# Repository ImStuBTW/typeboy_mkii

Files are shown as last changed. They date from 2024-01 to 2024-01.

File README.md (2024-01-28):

# The TypeBoy Mk II

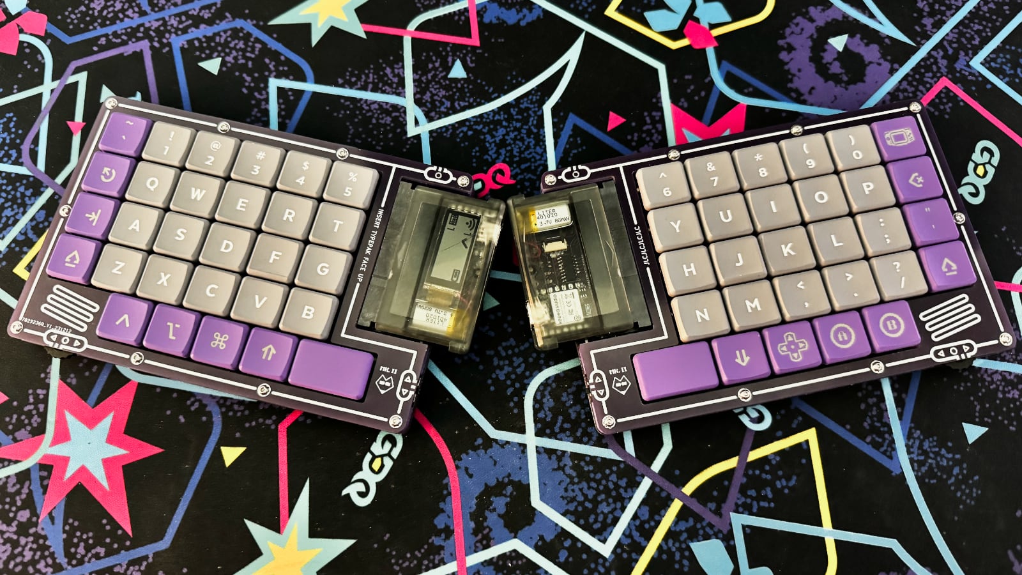
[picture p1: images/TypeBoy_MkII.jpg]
The TypeBoy Mark II Keyboard


The Mark II is an updated design to the original TypeBoy keyboard. It continues to leverage the "TypePak" cartridge to house the keyboard's microcontroller and other support circuitry. This revision of the TypeBoy uses a more traditional ortholinear keyboard layout, and replaces the previous 3D printed design with a PCB sandwich approach. For more information on the keyboard's background, please feel free to check out this companying blog post.

## Primary Features

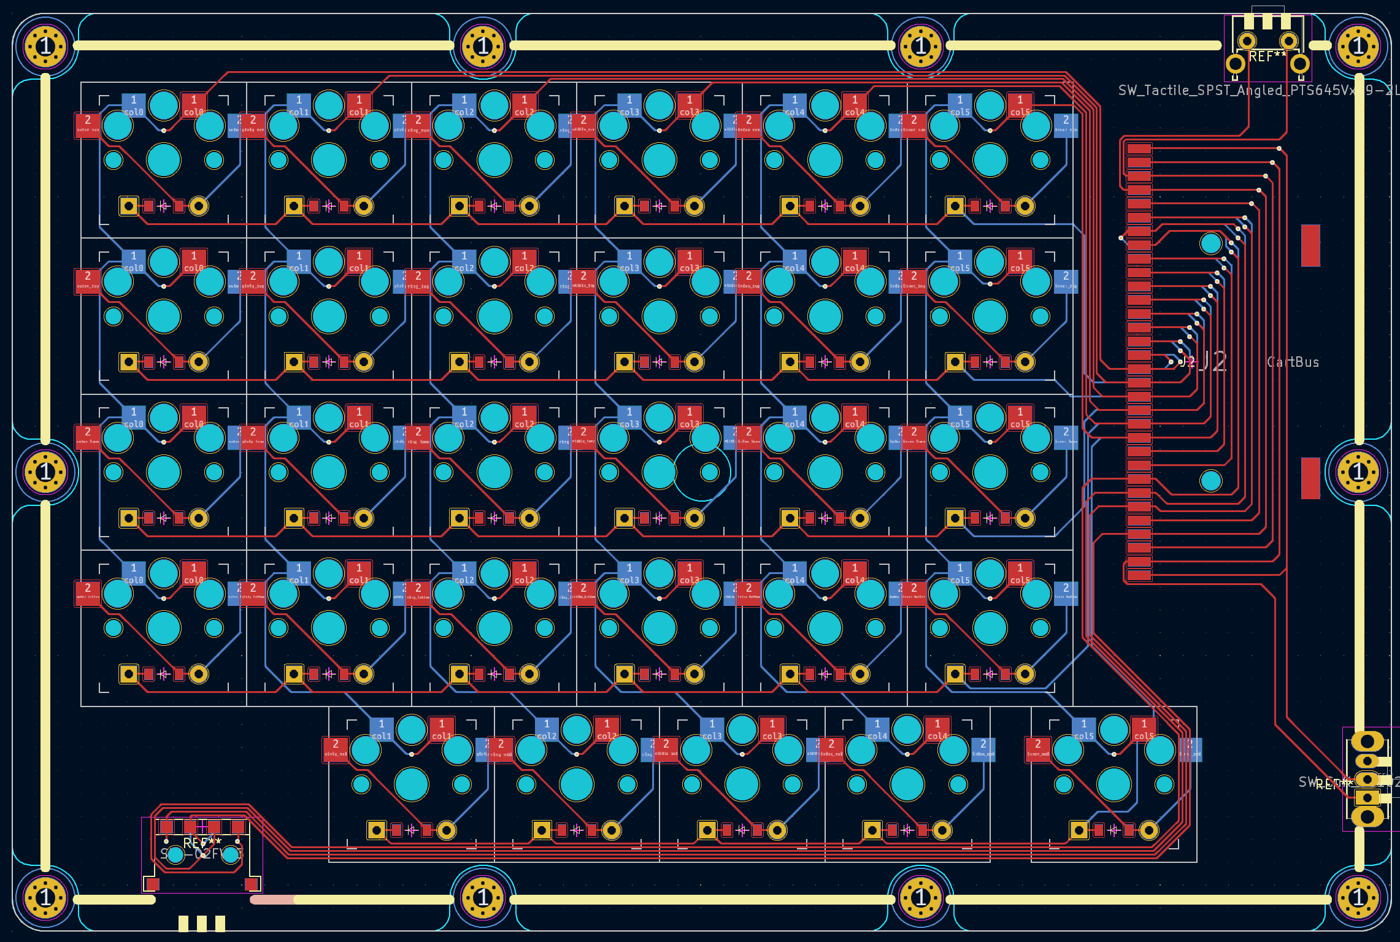
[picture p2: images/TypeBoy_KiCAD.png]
The TypeBoy Mk II KiCAD Diagram


* TypeBoy Cartridge Support (Integrated XAIO BLE, LiPo Battery, Shift Register, and Sharp Memory Display)
* 6x4+5 ortholinear layout with a staggered modifier row and enlarged space keys.
* Choc v1 switches with Choc spacing.
* SIQ-02FVS3 thumb wheel encoders (with pushbutton support).
* PCB sandwich design.
* ZMK support.

## Ergogen Outputs

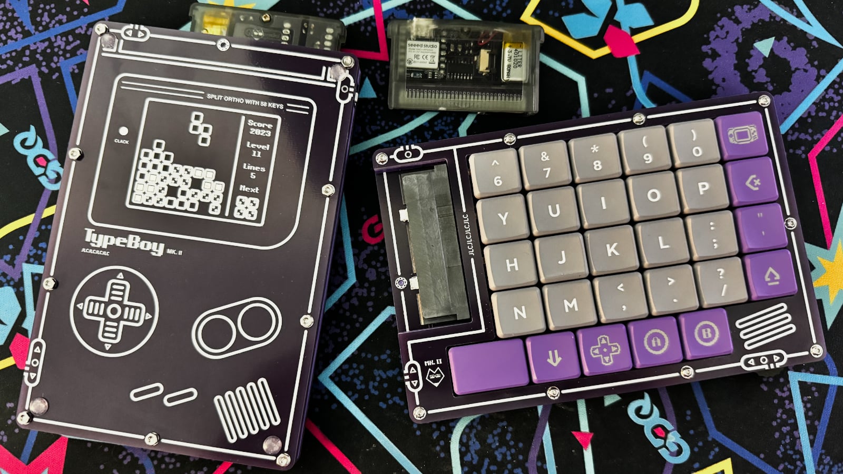
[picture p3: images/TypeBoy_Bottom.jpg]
The bottom PCB of the TypeBoy Mk II.


The TypeBoy Mk II was designed once again using the [Ergogen](https://github.com/ergogen/ergogen) keyboard layout generator. In this instance, Ergogen was used to create the PCB outputs for the top, middle, and bottom layers of the keyboard. The silkscreen designs were created in Figma and imported directly into the KiCAD outputs. The final routing for the middle layer was also performed in KiCAD.

## Additional Footprints

Ergogen v4 supports custom footprints! The TypeBoy colors outsides the lines and includes a few not included in the standard repo:

* buttonrightangle.js - A right angle pushbutton.
* gbareversible.js - A reversible game boy cartridge slot footprint based off of [Martin Refseth's KiCAD footprint](https://github.com/HDR/Game-Boy-KiCad-Library/blob/master/Footprints/DSL_Cartridge_Reader.kicad_mod).
* lowproro.js - A footprint for the SIQ-02FVS3 low profile rotary encoder. Used in an earlier TypeBoy design.
* mountinghole_m3.js - An M3 mounting hole footprint.
* spdt.js - A right angle power switch.

## Build of Materials

| Part | Amount | Price | Link |
| --- | --- | --- | ---- |
| TypePak Cartridges | 2 | $20 | https://github.com/ImStuBTW/typeboy_and_typepak/tree/main/typepak |
| TypeBoy Mk II PCBs Via JLCPCB | 3 (5 PCB Packs) | $45.00 USD (Incl. Shipping) | https://jlcpcb.com |
| Game Boy Cartridge Slot | 2 | $5.00 USD  | https://www.aliexpress.us/item/2255800103876564.html |
| SIQ-02FVS3 Thumb Wheel | 2 | $6.00 USD | https://www.aliexpress.us/item/3256804405904721.html |
| Right Angle Pushbutton | 2 | $1.00 USD | https://www.mouser.com/ProductDetail/642-MJTP1117 |
| Right Angle Switch | 2 | $1.50 USD | https://www.mouser.com/ProductDetail/612-EG1213 |
| Choc Hotswap Sockets | 58 | $12.00 USD  | https://www.aliexpress.us/item/3256803687338432.html |
| 1N4148 T4 Diodes | 58 | $3.00 USD | https://www.aliexpress.us/item/2255800498728983.html |
| Choc Switches | 58 | $28.00 USD  | https://www.aliexpress.us/item/3256805260407528.html |
| Choc Keycaps | Alphas + Mods  | $~60.00 USD | https://mkultra.click/mbk-legend-keycaps/ |
| 12mm M3 Screws | 18 | $2.00 USD | https://www.aliexpress.us/item/3256803547633472.html |
| M3 Washers | 54 | $10.00 USD  | https://www.aliexpress.us/item/3256804700714045.html |
| M3 Nuts | 18 | $5.00 USD | https://www.aliexpress.us/item/2255800148575548.html |
| Bumpons | 1 Pack | $10.00 USD | https://www.amazon.com/Adhesive-Bumper-106-PC-Spherical-Square/dp/B06XPCLN23/ |

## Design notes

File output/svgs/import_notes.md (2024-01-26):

These silkscreen .svg files were made in Figma. When importing these .svg files into KiCAD, resize them at a scaling factor of 3.7825. This isn't derrived from any particular mathmatical formula. It's just eyeballed.

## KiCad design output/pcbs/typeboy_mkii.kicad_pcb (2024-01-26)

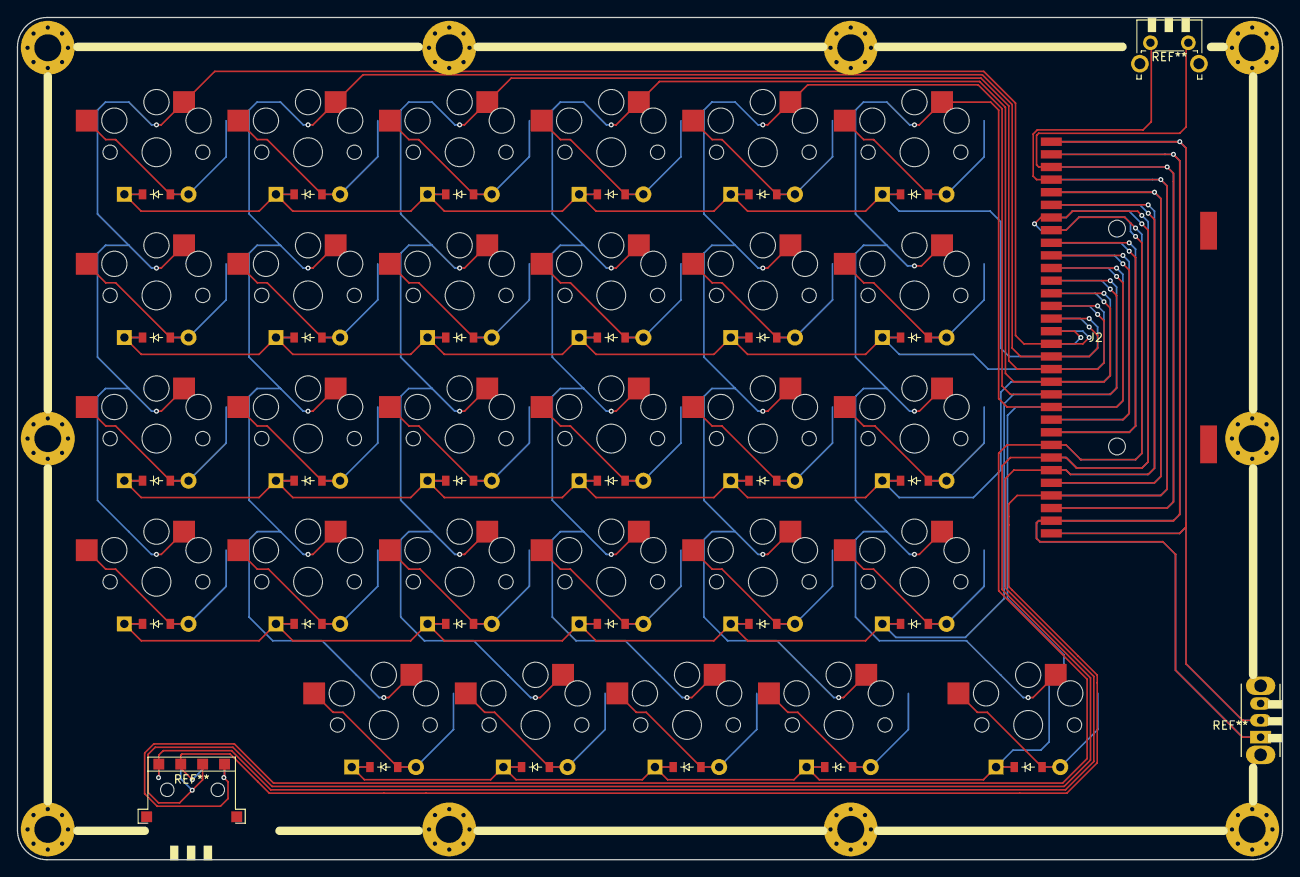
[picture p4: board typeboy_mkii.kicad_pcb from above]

Board: 2 copper layers, 150.2 x 100.0 mm, 59 parts (0 on the bottom side), 55 nets.

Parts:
D1, D2, D3, D4, D5, D6, D7, D8, D9, D10, D11, D12, D13, D14, D15, D16, D17, D18, D19, D20, D21, D22, D23, D24, D25, D26, D27, D28, D29: ComboDiode
J2: CartBus; GBA_Reversible_Cart_Reader
S1, S2, S3, S4, S5, S6, S7, S8, S9, S10, S11, S12, S13, S14, S15, S16, S17, S18, S19, S20, S21, S22, S23, S24, S25, S26, S27, S28, S29: PG1350

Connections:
BATIN: J2.2, J2.31, J2.34, J2.63
BATOUT: J2.1, J2.32, J2.33, J2.64
GND: J2.4, J2.29, J2.36, J2.61
IO_CS: J2.9, J2.56
LCD_CS: J2.16, J2.49
MISO: J2.7, J2.25, J2.40, J2.58
MOSI: J2.6, J2.59
NFC0: J2.26, J2.39
NFC1: J2.27, J2.38
RST: J2.3, J2.30, J2.35, J2.62
SCK: J2.8, J2.57
VCC: J2.5, J2.28, J2.37, J2.60
col0: J2.17, J2.48, S1.1, S2.1, S3.1, S4.1
col1: J2.18, J2.47, S5.1, S6.1, S7.1, S8.1, S9.1
col2: J2.19, J2.46, S10.1, S11.1, S12.1, S13.1, S14.1
col3: J2.20, J2.45, S15.1, S16.1, S17.1, S18.1, S19.1
col4: J2.21, J2.44, S20.1, S21.1, S22.1, S23.1, S24.1
col5: J2.22, J2.43, S25.1, S26.1, S27.1, S28.1, S29.1
col6: J2.23, J2.42
col7: J2.24, J2.41
index_bottom: D21.2, S21.2
index_home: D22.2, S22.2
index_mod: D20.2, S20.2
index_num: D24.2, S24.2
index_top: D23.2, S23.2
inner_bottom: D26.2, S26.2
inner_home: D27.2, S27.2
inner_mod: D25.2, S25.2
inner_num: D29.2, S29.2
inner_top: D28.2, S28.2
middle_bottom: D16.2, S16.2
middle_home: D17.2, S17.2
middle_mod: D15.2, S15.2
middle_num: D19.2, S19.2
middle_top: D18.2, S18.2
outer_bottom: D1.2, S1.2
outer_home: D2.2, S2.2
outer_num: D4.2, S4.2
outer_top: D3.2, S3.2
pinky_bottom: D6.2, S6.2
pinky_home: D7.2, S7.2
pinky_mod: D5.2, S5.2
pinky_num: D9.2, S9.2
pinky_top: D8.2, S8.2
ring_bottom: D11.2, S11.2
ring_home: D12.2, S12.2
ring_mod: D10.2, S10.2
ring_num: D14.2, S14.2
ring_top: D13.2, S13.2
row0: D4.1, D9.1, D14.1, D19.1, D24.1, D29.1, J2.15, J2.50
row1: D3.1, D8.1, D13.1, D18.1, D23.1, D28.1, J2.14, J2.51
row2: D2.1, D7.1, D12.1, D17.1, D22.1, D27.1, J2.13, J2.52
row3: D1.1, D6.1, D11.1, D16.1, D21.1, D26.1, J2.12, J2.53
row4: D5.1, D10.1, D15.1, D20.1, D25.1, J2.11, J2.54
row5: J2.10, J2.55

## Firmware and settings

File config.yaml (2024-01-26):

units:
  # Choc keycap dimensions
  capx: 17  
  capy: 16
  # Choc key spacing dimensions
  kx: 18    
  ky: 17

  # Constants
  $default_height: 0  # Points invisible by default unless height/width explicitly set
  $default_width: 0
  m3_diameter: 3.2

points.zones:
  # Define points for Zenestra case outline
  extent:
    anchor.shift: [150, -180]  # Fix placement on KiCAD sheet
    key:
      name: "{{zone.name}}_{{row}}_{{col.name}}"
      padding: 100 / 2
    rows:
      bottom:
      middle:
      top:
    columns:
      left:
      left_second.key.spread: 51.267
      right_second.key.spread: 47.667
      right.key.spread: 51.267
  extent_center.anchor:
    aggregate.parts:
    - extent_middle_left
    - extent_middle_right

  # Define mounting hole points.
  mount_top_left.anchor:
    ref: extent_top_left
    shift: [3.6, -3.6]
  mount_top_left_second.anchor:
    ref: extent_top_left_second
    shift: [0, -3.6]
  mount_top_right_second.anchor:
    ref: extent_top_right_second
    shift: [0, -3.6]
  mount_top_right.anchor:
    ref: extent_top_right
    shift: [-3.6, -3.6]
  mount_middle_left.anchor:
    ref: extent_middle_left
    shift: [3.6, 0]
  mount_middle_right.anchor:
    ref: extent_middle_right
    shift: [-3.6, 0]
  mount_bottom_left.anchor:
    ref: extent_bottom_left
    shift: [3.6, 3.6]
  mount_bottom_left_second.anchor:
    ref: extent_bottom_left_second
    shift: [0, 3.6]
  mount_bottom_right_second.anchor:
    ref: extent_bottom_right_second
    shift: [0, 3.6]
  mount_bottom_right.anchor:
    ref: extent_bottom_right
    shift: [-3.6, 3.6]

  # Define the actual points for our keys.
  key_matrix:
    # Move Key Matrix location inside the PCB points.
    anchor:
      - ref: extent_top_left
        shift: [0.5kx,  -3ky + 0.5ky]  # Top left
      - shift: [0.5+7, -41.5]
    # Set Default Choc Spacing
    key:
      width: capx
      height: capy
      spread: kx
      padding: ky
    # Column Definitions
    columns:
      outer:
        # Skip the key under "Shift"
        rows.mod.skip: true
        key.column_net: col0
      pinky:
        # Shift the mod row over by half a key, then shift the rest back.
        rows.bottom.shift: [-0.5cx, 0]
        rows.mod.shift: [0.5cx, 0]
        key.column_net: col1
      ring:
        rows.bottom.shift: [-0.5cx, 0]
        rows.mod.shift: [0.5cx, 0]
        key.column_net: col2
      middle:
        rows.bottom.shift: [-0.5cx, 0]
        rows.mod.shift: [0.5cx, 0]
        key.column_net: col3
      index:
        rows.bottom.shift: [-0.5cx, 0]
        rows.mod.shift: [0.5cx, 0]
        key.column_net: col4
      inner:
        # Use a large 1.5-wide space key.
        rows.bottom.shift: [-0.75cx, 0]
        rows.mod.shift: [0.75cx, 0]
        rows.mod.width: 1.5cx
        key.column_net: col5
    # Row Definitions
    rows:
      mod.row_net: row4
      bottom.row_net: row3
      home.row_net: row2
      top.row_net: row1
      num.row_net: row0
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
